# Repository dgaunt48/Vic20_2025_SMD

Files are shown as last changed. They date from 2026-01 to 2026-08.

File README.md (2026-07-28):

# Vic20_2025_SMD
Vic20 Recreation using only parts currently manufactured.

NOTE: Original (PAL) VIC chip is still required in first prototype, will be optional in next revision.

## First Prototype Boards
Hooked up the test harness and passed all tests in DiagROM.

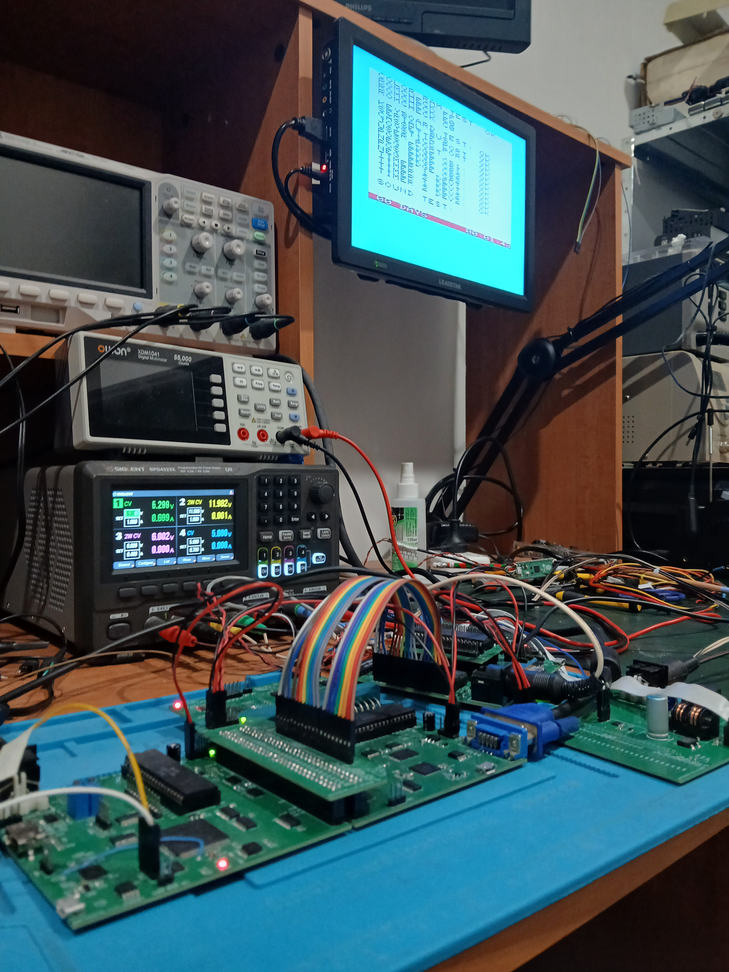
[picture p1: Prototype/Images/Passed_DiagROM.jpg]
Passed DiagROM Passed Diag ROM


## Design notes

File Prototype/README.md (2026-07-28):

# Vic20_2025_SMD_PROTOTYPE

## Added VIA 6522 to FPGA.
Hacked the hell out of the I/O board (all that mess on the left) to interface with an iCE40 FPGA. There should be just enough pins to add both VIA's to the $10 iCE40 that forms the core of this build.  Only VIA 2 (the keyboard scan and serial edge triggers) is running on the FPGA at the moment. A Real 6522 VIA (near the serial connector) is working together nicely with the FPGA VIA core to complete the serial I/O.

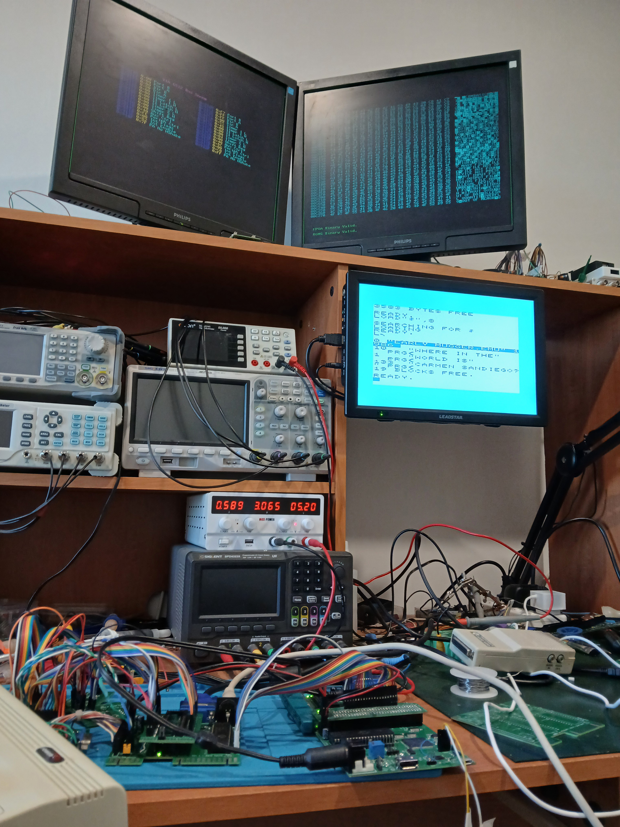
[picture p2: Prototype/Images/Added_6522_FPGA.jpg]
New VIA Core


## First Prototype Board.
RP2350A is only there as a HDMI encoder.
ICE40 FPGA has main 5k RAM, Colour RAM, Character ROM and all glue logic.
RP2350B configures FPGA core and 128k RAM chip used For Expansion RAM / ROM on 6502 Side Of Bus.  RAM IC gets copys of ROMS (including KERNAL and BASIC) before banking and R/W access is enforced.  

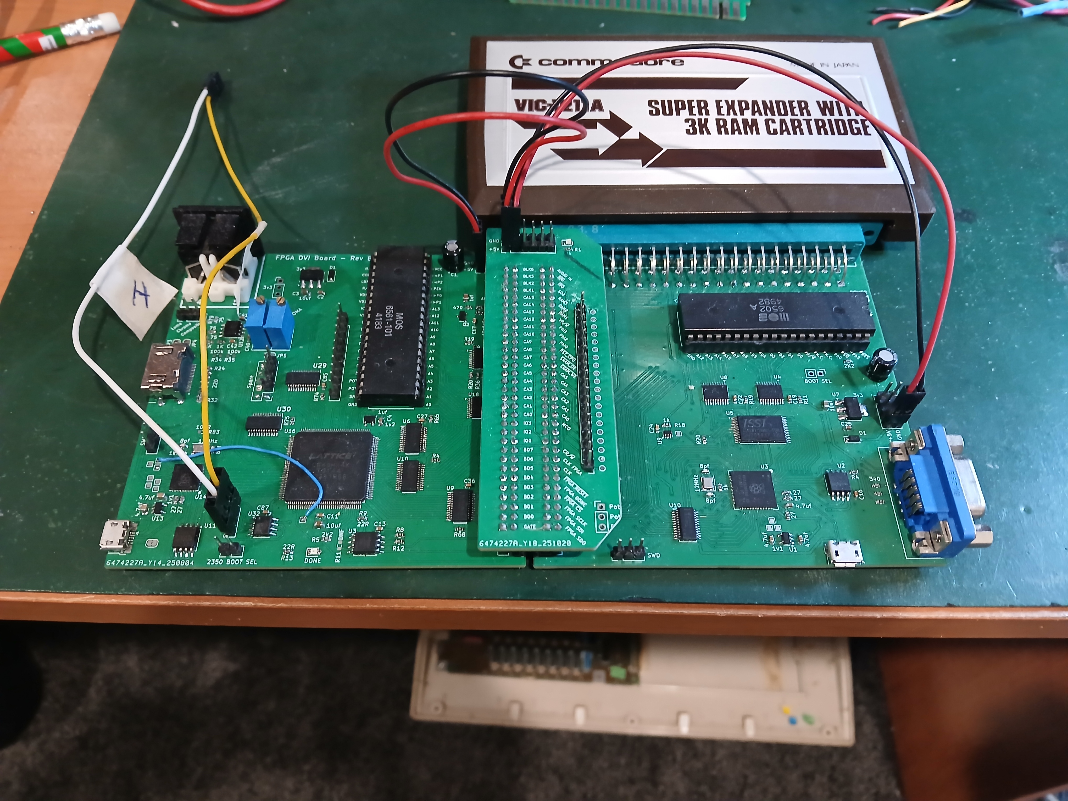
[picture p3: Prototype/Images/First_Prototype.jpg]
First Prototype First Prototype Board


## First Experiments With The Vic20

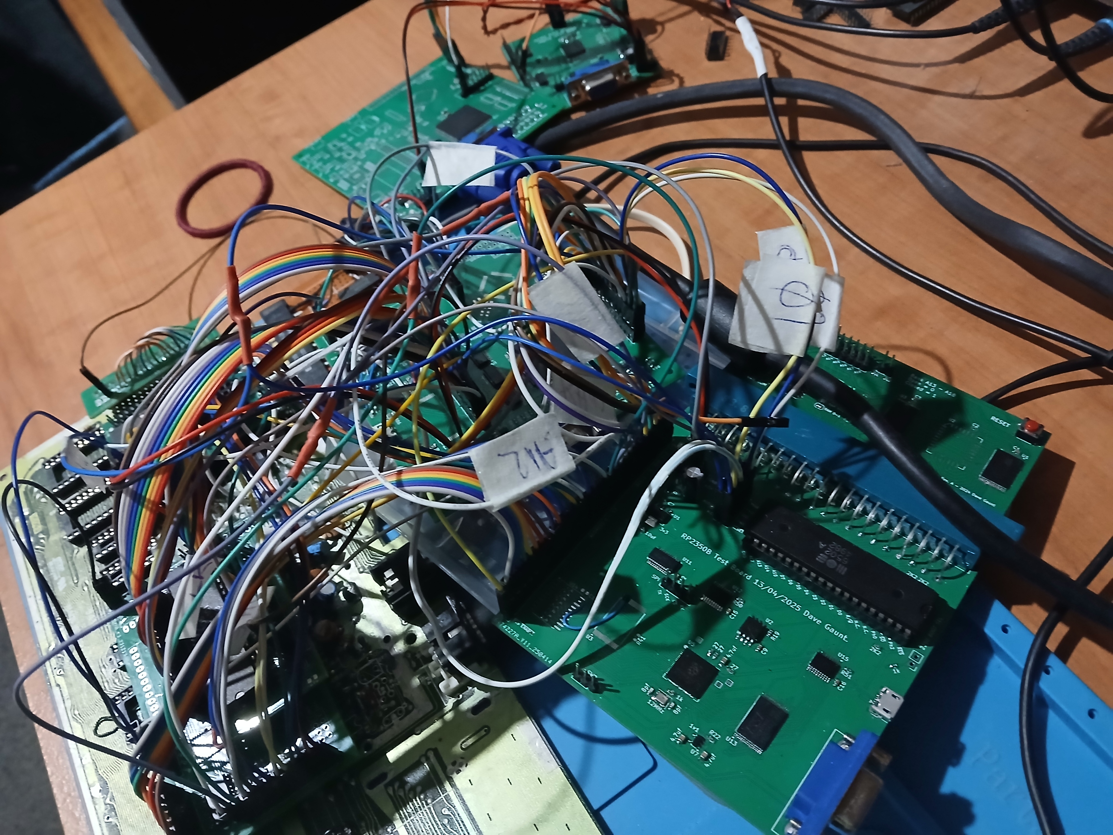
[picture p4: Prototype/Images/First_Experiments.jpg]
First Experiments First Experiments With The Vic20


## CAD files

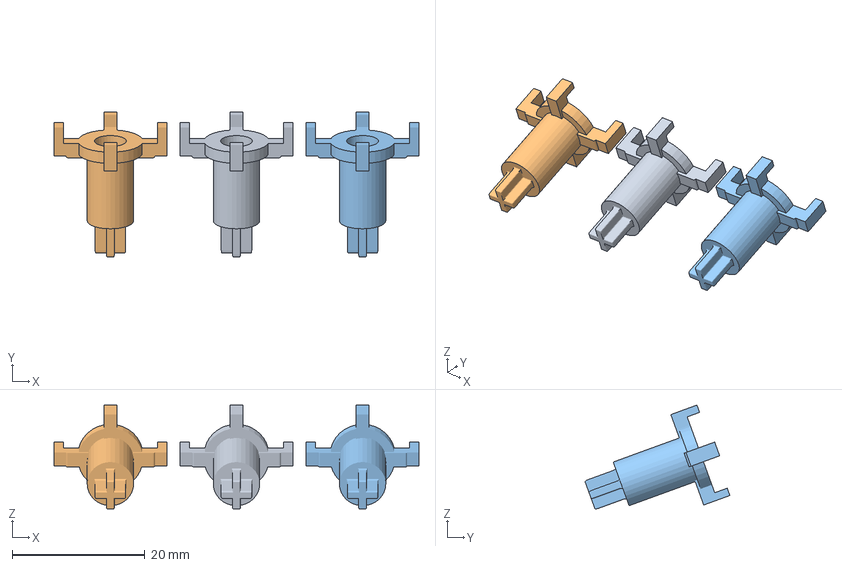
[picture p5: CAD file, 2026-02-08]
3d Prints/Vic20CR_KeyStem/CE3S1PRO_KeyStem_Vic20CR_NoSpring.3mf
55.0 x 21.8 x 15.7 mm
KeyStem_Vic20_CR_NoSprings.stl
KeyStem_Vic20_CR_NoSprings.stl(1)
KeyStem_Vic20_CR_NoSprings.stl(2)

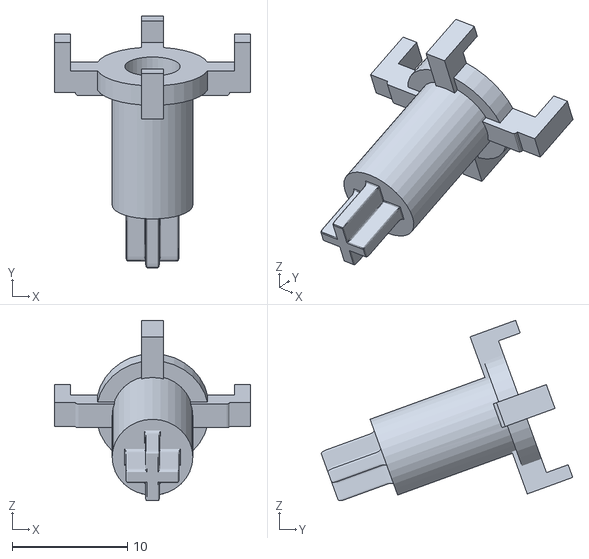
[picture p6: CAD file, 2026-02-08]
3d Prints/Vic20CR_KeyStem/KeyStem_Vic20CR_NoSpring.stl
17.0 x 21.8 x 15.7

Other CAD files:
3d Prints/Vic20CR_KeyStem/Vic20_KeyStem.blend

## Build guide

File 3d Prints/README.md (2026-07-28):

# Vic20CR_KeyStem
3D printed key stem for Vic20 CR (no spring version)

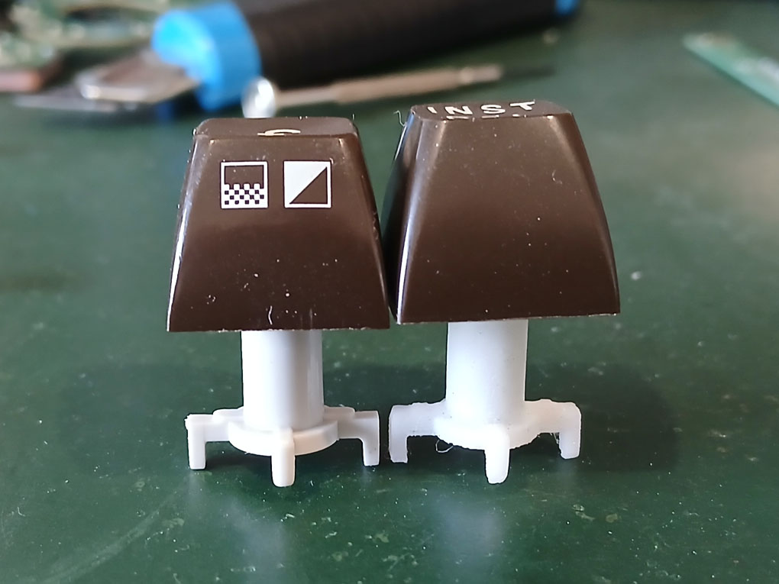
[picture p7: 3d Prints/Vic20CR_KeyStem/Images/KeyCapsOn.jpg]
KeyCaps Key Caps On


Comparison:  Original on Left / 3d Print On Right.

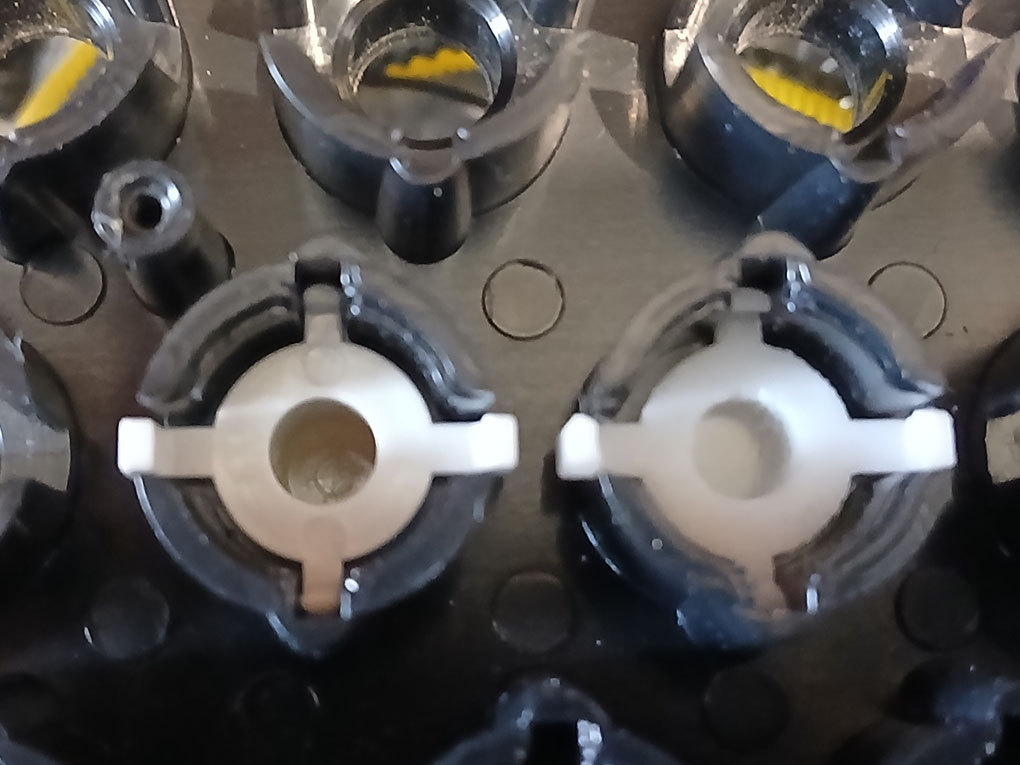
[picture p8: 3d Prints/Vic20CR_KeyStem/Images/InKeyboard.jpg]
KeyBoard In Keyboard


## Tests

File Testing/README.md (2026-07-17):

# Source Code For Vic 20 SMD Recreation
VIA 6522 FPGA Core is now running and passing the diagnostic cartridge tests.

## DiagnosticROM
Cut down diagnostic 6502 source so i can target individual test conditions.  Full Source 
to vc-20-diag.324173-01_blk5.bin is in my CBM_Flash_ROMs\Vic20_DiagROM repository.

## VIA_6522_Emulation
Start of a software emulated 6522.  Will probably end up with the VIA's on the iCE40,
but wanted to do some tests to see if emulation is a viable alternative.

## VIA_6522_Snoop
Rp2350 Bus Snoop program to display all register reads and writes to both VIA IC's on a running Vic20.

## VIA_6522_Tester
RP2350 program to bitbang test conditions into a real 6522.  At the moment it is
only setting up timer 1 to loop forever, triggering IRQ interrupts every 6 clocks.

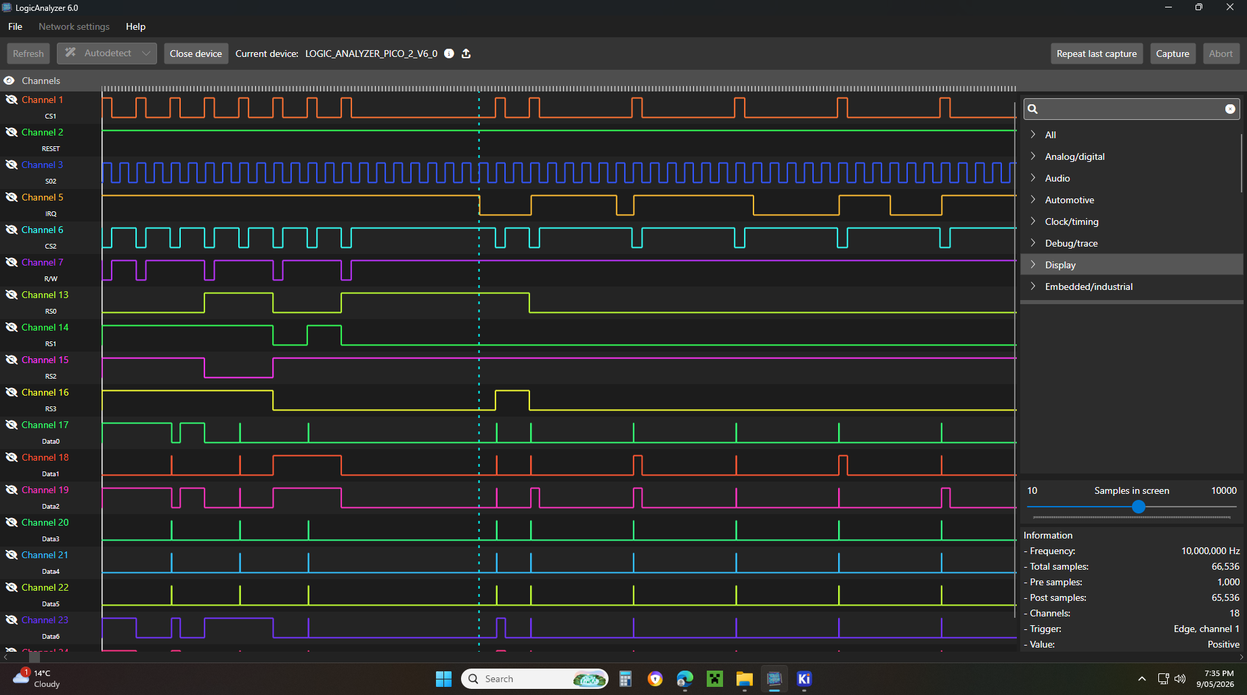
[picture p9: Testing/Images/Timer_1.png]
6522 Running Timer 1


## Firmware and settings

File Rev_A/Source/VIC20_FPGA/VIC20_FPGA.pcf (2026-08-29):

set_io bPhase2Clock			1		# Vic20 1,108,404 Hz clock
set_io bRead				3		# Read = 1 / Write = 0
set_io bCS_n				7		# Chip Select Active Low
set_io bCA1					2
set_io bCB1					4

set_io nRS[0]				73		# 4 Bit Register Address
set_io nRS[1]				75
set_io nRS[2]				78
set_io nRS[3]				80
# set_io bCS				82		# nRS[4]  Chip Select Active Hi
set_io bCS					83		# nRS[5]  Chip Select Active Hi

set_io bFPGACoreClock		93		# 25Mhz FPGA Clock

set_io nData[0]				97		# 8 Bit Data Bus
set_io nData[1]				99
set_io nData[2]				102
set_io nData[3]				105
set_io nData[4]				107
set_io nData[5]				110
set_io nData[6]				106
set_io nData[7]				104

set_io bCA2					112
set_io bCB2					114
set_io bIRQ_n				119		# IRQ_n Active Low Open Drain IRQ Signal
set_io bReset_n				117		# Reset VIA Active Low

set_io nPortA[0]			120		# 8 Bit IO Data Port A
set_io nPortA[1]			122
set_io nPortA[2]			125
set_io nPortA[3]			134
set_io nPortA[4]			135
set_io nPortA[5]			130
set_io nPortA[6]			124
set_io nPortA[7]			121

set_io nPortB[0]			136		# 8 Bit IO Data Port B
set_io nPortB[1]			138
set_io nPortB[2]			141
set_io nPortB[3]			143
set_io nPortB[4]			144
set_io nPortB[5]			142
set_io nPortB[6]			139
set_io nPortB[7]			137

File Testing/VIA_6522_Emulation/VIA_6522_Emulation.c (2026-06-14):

//------------------------------------------------------------------------------------------------
//---- VIA 6522 ... 2026 Dave Gaunt                                                           ----
//------------------------------------------------------------------------------------------------
//---- Version 0.1                                                                            ----
//------------------------------------------------------------------------------------------------
#include <stdio.h>
#include "types.h"
#include "pico/stdlib.h"
#include "pico/multicore.h"

#include "vga111.h"

enum device_pins {
	PIN_RED = 0,
	PIN_GREEN,
	PIN_BLUE,
	PIN_S02_READ,
	PIN_HSYNC = 8,
	PIN_VSYNC,

	PIN_RESET,
	PIN_ADDRESS_CS1,		/* ADDRESS BIT 4 OR 5 On VIC */
	PIN_IO0,				/* CS2 ACTIVE LOW */
	PIN_READ_WRITE,
	PIN_IRQ,

	PIN_DATA_BIT0,
	PIN_DATA_BIT1,
	PIN_DATA_BIT2,
	PIN_DATA_BIT3,
	PIN_DATA_BIT4,
	PIN_DATA_BIT5,
	PIN_DATA_BIT6,
	PIN_DATA_BIT7,

	PIN_CLK,				/* S02 - Data Transfer Occurs Only When Phase 2 Clock Is High */
	PIN_ADDRESS_BIT0,
	PIN_ADDRESS_BIT1,
	PIN_ADDRESS_BIT2,
	PIN_ADDRESS_BIT3,

	PIN_PORT_A = 32,
	PIN_PORT_B = 40
};

static_assert(23 == PIN_CLK, "Clock must be on PIN 23!");

//------------------------------------------------------------------------------------------------
//----                                                                                        ----
//------------------------------------------------------------------------------------------------
enum via_register_names
{
	VIA_REG_PORTB = 0,
	VIA_REG_PORTA,
	VIA_REG_DATA_DIRB,
	VIA_REG_DATA_DIRA,
	VIA_REG_TIMER1_L,
	VIA_REG_TIMER1_H,
	VIA_REG_TIMER1_LATCH_L,
	VIA_REG_TIMER1_LATCH_H,
	VIA_REG_TIMER2_L,
	VIA_REG_TIMER2_H,
	VIA_REG_SHIFT,
	VIA_REG_AUXILIARY_CONTROL,
	VIA_REG_PERIPHERAL_CONTROL,
	VIA_REG_INTERRUPT_FLAGS,
	VIA_REG_INTERRUPT_ENABLE,
	VIA_REG_PORTA_NO_HANDSHAKE
};

// Register Name Strings For Debug View.
static const char s_aszRegisterNames[16][16] =
{
/*  "123456789ABCDEF"	*/
	"Port B",
	"Port A",
	"Dir B",
	"Dir A",
	"Timer 1 L",
	"Timer 1 H",
	"T1 Latch L",
	"T1 Latch H",
	"Timer 2 L",
	"Timer 2 H",
	"Shift Reg",
	"Aux Ctrl",
	"Periph Ctrl",
	"Int Flags",
	"Int Enable",
	"PA No HShake"
/*  "123456789ABCDEF"	*/
};

enum via_irq_flags
{
	VIA_IRQ_CA2 = 0,
	VIA_IRQ_CA1,
	VIA_IRQ_SHIFT,
	VIA_IRQ_CB2,
	VIA_IRQ_CB1,
	VIA_IRQ_TIMER2,
	VIA_IRQ_TIMER1,
	VIA_IRQ_SET_CLR
};

typedef struct
{
	union
	{
		u8 m_aReg[16];
		struct
		{
			u8 m_u8PortB;					/* 0 */
			u8 m_u8PortA;					/* 1 */
			u8 m_uDataDirB;					/* 2 */
			u8 m_uDataDirA;					/* 3 */
			union
			{
				u16	m_uTimer1;
				struct
				{
					u8 m_uTimer1_L;			/* 4 */
					u8 m_uTimer1_H;			/* 5 */
				};
			};
			union
			{
				u16	m_uTimer1_Latch;
				struct
				{
					u8 m_uTimer1_Latch_L;	/* 6 */
					u8 m_uTimer1_Latch_H;	/* 7 */
				};
			};
			union
			{
				u16	m_uTimer2;
				struct
				{
					u8 m_uTimer2_L;			/* 8 */
					u8 m_uTimer2_H;			/* 9 */
				};
			};
			u8 m_uShiftReg;					/* A */
			u8 m_uAuxiliaryCtrl;			/* B */
			u8 m_uPeripheralCtrl;			/* C */
			u8 m_uInterruptFlags;			/* D */
			u8 m_uInterruptEnable;			/* E */
			u8 m_u8PortA_NoHandshake;		/* F */
		};
	};
} ViaRegisters;
static_assert(sizeof(ViaRegisters) == 16);

static volatile ViaRegisters s_viaRegs = {0};

typedef struct
{
	u8	m_uOffset;
	u8	m_uData;
} RegisterBuffer;

static volatile RegisterBuffer s_aRegBuffer[16];
static volatile u8 s_uRegHead = 15;
static volatile u8 s_uRegTail = 15;

//------------------------------------------------------------------------------------------------
//----                                                                                        ----
//------------------------------------------------------------------------------------------------
static void __not_in_flash_func(function_core1)(void)
{
	save_and_disable_interrupts();

	u32 uS02 = 1;
 	u32 uLow32Pins = gpioc_lo_in_get();

	// Wait for IO0 To Return Hi AND S02 To Assert Low
	while ( (0 == ((uLow32Pins >> PIN_IO0) & 1)) || (1 == ((uLow32Pins >> PIN_CLK) & 1)) )
		uLow32Pins = gpioc_lo_in_get();

	while(true)
 	{
		while(true)
		{
	 		uLow32Pins = gpioc_lo_in_get();

			// If S02 Is Hi
			if ((uLow32Pins >> PIN_CLK) & 1)
			{
				if (0 == uS02)
				{
					// And IO0 Is Low Then Process VIA IO
					if ((0 == ((uLow32Pins >> PIN_IO0) & 1)) && ((uLow32Pins >> PIN_ADDRESS_CS1) & 1))
						break;

						// We Have Finished For This Transition Of S02
					uS02 = 1;
				}
			}
			else
			{
				if (1 == uS02)
				{
					// S02 Has Transitioned From Hi To Low - Check If The Timer Is Non-Zero
					if (0 != s_viaRegs.m_uTimer1)
					{
						// If the Timer Will Go To Zero
						if (1 == s_viaRegs.m_uTimer1)
						{
							s_viaRegs.m_uTimer1 = s_viaRegs.m_uTimer1_Latch;
							s_viaRegs.m_uInterruptFlags |= (1 << VIA_IRQ_TIMER1);
						}
						else
						{
							s_viaRegs.m_uTimer1--;
						}
					}

					u32 uHiPins = gpioc_hi_in_get();
					s_viaRegs.m_u8PortA = (uHiPins >> (PIN_PORT_A - 32)) & 0xFF;
					s_viaRegs.m_u8PortA_NoHandshake = (uHiPins >> (PIN_PORT_A - 32)) & 0xFF;
				}

				// S02 Has Transitioned From Hi To Low
				uS02 = 0;
			}
		}

		if ( 0 == ((uLow32Pins >> PIN_READ_WRITE) & 1) )
		{
			delay_40ns();
			uLow32Pins = gpioc_lo_in_get();
			const u32 uRegister = (uLow32Pins >> PIN_ADDRESS_BIT0) & 0xF;
			const u32 uData = (uLow32Pins >> PIN_DATA_BIT0) & 0xFF;

			switch(uRegister)
			{
				case VIA_REG_PORTB:
					gpioc_hi_out_xor((gpioc_hi_out_get() ^ (uData << (PIN_PORT_B - 32))) & (0xFF << (PIN_PORT_B - 32)));
					s_viaRegs.m_u8PortB ^= (s_viaRegs.m_u8PortB ^ uData) & s_viaRegs.m_uDataDirB;
				break;

				case VIA_REG_PORTA:
					gpioc_hi_out_xor((gpioc_hi_out_get() ^ (uData << (PIN_PORT_A - 32))) & (0xFF << (PIN_PORT_A - 32)));
					s_viaRegs.m_u8PortA ^= (s_viaRegs.m_u8PortA ^ uData) & s_viaRegs.m_uDataDirA;
				break;

				case VIA_REG_DATA_DIRB:
					gpioc_hi_oe_xor((gpioc_hi_oe_get() ^ (uData << (PIN_PORT_B - 32))) & (0xFF << (PIN_PORT_B - 32)));
					s_viaRegs.m_uDataDirB = uData;
				break;

				case VIA_REG_DATA_DIRA:
					gpioc_hi_oe_xor((gpioc_hi_oe_get() ^ (uData << (PIN_PORT_A - 32))) & (0xFF << (PIN_PORT_A - 32)));
					s_viaRegs.m_uDataDirA = uData;
				break;

				default:
					// Push Register Set Onto Ring Buffer.
					const u8 uRegTail = (s_uRegTail + 1) & 15;
					assert(uRegTail != s_uRegHead);		// Ring Buffer Is Full !!!
					s_aRegBuffer[uRegTail].m_uOffset = (u8)uRegister;
					s_aRegBuffer[uRegTail].m_uData = (u8)uData;
					s_uRegTail = uRegTail;
				break;
			}

			// Wait for IO0 To Return Hi OR S02 To Assert Low
			// while ( (0 == ((uLow32Pins >> PIN_IO0) & 1)) && (1 == ((uLow32Pins >> PIN_CLK) & 1)) )
			// 	uLow32Pins = gpioc_lo_in_get();
		}
		else
		{
			const u32 uRegister = (uLow32Pins >> PIN_ADDRESS_BIT0) & 0xF;
			const u8 uData = s_viaRegs.m_aReg[uRegister];
			gpio_put_masked((0xFF << PIN_DATA_BIT0), (uData << PIN_DATA_BIT0));

			// Set All Data Bits To Output
			gpio_set_dir_masked((0xFF << PIN_DATA_BIT0), (0xFF << PIN_DATA_BIT0));

			// Wait for IO0 To Return Hi OR S02 To Assert Low
			while ( (0 == ((uLow32Pins >> PIN_IO0) & 1)) && (1 == ((uLow32Pins >> PIN_CLK) & 1)) )
				uLow32Pins = gpioc_lo_in_get();

			// Get Off The Bus
			gpio_set_dir_masked((0xFF << PIN_DATA_BIT0), 0);

			// If We Read Timer1 Low Byte Clear The IRQ Flag.
			if (VIA_REG_TIMER1_L == uRegister)
				s_viaRegs.m_uInterruptFlags &= ~(1 << VIA_IRQ_TIMER1);
		}
	}
}

//------------------------------------------------------------------------------------------------
//----                                                                                        ----
//------------------------------------------------------------------------------------------------
void ProcessVIA(void)
{
	// Are There Any Register Writes On The Ring Buffer?
	if (s_uRegHead != s_uRegTail)
	{
		const u8 uRegister = s_aRegBuffer[s_uRegHead].m_uOffset & 15;
		const u8 uData = s_aRegBuffer[s_uRegHead].m_uData;

		switch(uRegister)
		{
			case VIA_REG_TIMER1_L:
			{
				// Write Data Into The Low Order Latch... Not The Counter!!!
				s_viaRegs.m_uTimer1_Latch_L = uData;
			}
			break;

			case VIA_REG_TIMER1_H:
			{
				s_viaRegs.m_uTimer1_Latch_H = uData;
				s_viaRegs.m_uTimer1 = s_viaRegs.m_uTimer1_Latch;
				s_viaRegs.m_uInterruptFlags &= ~(1 << VIA_IRQ_TIMER1);
			}
			break;

			case VIA_REG_TIMER1_LATCH_L:
			{
				s_viaRegs.m_uTimer1_Latch_L = uData;
			}
			break;

			case VIA_REG_TIMER1_LATCH_H:
			{
				s_viaRegs.m_uTimer1_Latch_H = uData;
				s_viaRegs.m_uInterruptFlags &= ~(1 << VIA_IRQ_TIMER1);
			}
			break;

			case VIA_REG_INTERRUPT_FLAGS:
			{
				if (uData & 0x80)
				{
					// Bit 7 Is High So Enable Any Specified Interrupts.
					s_viaRegs.m_uInterruptFlags |= (uData & 0x7F);
				}
				else
				{
					// Bit 7 Is Low So Disable Any Specified Interrupts.
					s_viaRegs.m_uInterruptFlags &= (~uData & 0x7F);
				}

				if (s_viaRegs.m_uInterruptFlags)
					s_viaRegs.m_uInterruptFlags |= (1 << VIA_IRQ_SET_CLR);
			}
			break;

			case VIA_REG_INTERRUPT_ENABLE:
			{
				if (uData & 0x80)
				{
					// Bit 7 Is High So Enable Any Specified Interrupts.
					s_viaRegs.m_uInterruptEnable |= (uData & 0x7F);
				}
				else
				{
					// Bit 7 Is Low So Disable Any Specified Interrupts.
					s_viaRegs.m_uInterruptEnable &= (~uData & 0x7F);
				}
			}
			break;

			default:
			s_viaRegs.m_aReg[uRegister] = uData;
		}

		// FIXME!!!!! THIS SHOULD BE A PRE INCREMENT!!!!!
		s_uRegHead = (s_uRegHead + 1) & 15;
	}

	const u8 uInterrupFlags = s_viaRegs.m_uInterruptFlags & s_viaRegs.m_uInterruptEnable;

	// If Any Enabled Interrupt Is Flagged The Set The Hi Bit
	s_viaRegs.m_uInterruptFlags = (uInterrupFlags) ? (1 << VIA_IRQ_SET_CLR) | uInterrupFlags : 0;

	// Reflect The IRQ Bit On The IO Pin.
	gpio_put(PIN_IRQ, ((~s_viaRegs.m_uInterruptFlags >> VIA_IRQ_SET_CLR) & 1));
}

//------------------------------------------------------------------------------------------------
//----                                                                                        ----
//------------------------------------------------------------------------------------------------
int main()
{
	stdio_init_all();

	gpio_init(PIN_CLK);
	gpio_set_dir(PIN_CLK, GPIO_IN);

	// Clock Is Currently Looped Back So PIN_CLK Can Be Created And Read By The Test Program.
	gpio_init(PIN_S02_READ);
	gpio_set_dir(PIN_S02_READ, GPIO_IN);

	// CS1 Is Address Line 4 Or 5 On The VIC.
	gpio_init(PIN_ADDRESS_CS1);
	gpio_set_dir(PIN_ADDRESS_CS1, GPIO_IN);

	gpio_init(PIN_IO0);
	gpio_set_dir(PIN_IO0, GPIO_IN);

	gpio_init(PIN_READ_WRITE);
	gpio_set_dir(PIN_READ_WRITE, GPIO_IN);

	// IRQ Active Low
	gpio_init(PIN_IRQ);
	gpio_set_dir(PIN_IRQ, GPIO_OUT);
	gpio_put(PIN_IRQ, true);

	// Set All Data Pins To Input
	for(u32 uPin=PIN_DATA_BIT0; uPin<=PIN_DATA_BIT7; ++uPin)
	{
		gpio_init(uPin);
		gpio_set_dir(uPin, GPIO_IN);
	}

	// Set All Address Pins To Input
	for(u32 uPin=PIN_ADDRESS_BIT0; uPin<=PIN_ADDRESS_BIT3; ++uPin)
	{
		gpio_init(uPin);
		gpio_set_dir(uPin, GPIO_IN);
	}

	gpio_init(PIN_RESET);
	gpio_set_dir(PIN_RESET, GPIO_IN);

	for(u32 uPinIndex=0; uPinIndex<8; ++uPinIndex)
	{
		gpio_init(PIN_PORT_A + uPinIndex);
		gpio_init(PIN_PORT_B + uPinIndex);

		gpio_set_dir(PIN_PORT_A + uPinIndex, GPIO_IN);
		gpio_set_dir(PIN_PORT_B + uPinIndex, GPIO_IN);

		gpio_pull_up(PIN_PORT_A + uPinIndex);
		gpio_pull_up(PIN_PORT_B + uPinIndex);
	}

	multicore_launch_core1(function_core1);

	vga_Init(PIN_RED, PIN_HSYNC, PIN_VSYNC);
	vga_FilledRect(0, 0, VGA_RESOLUTION_X, VGA_RESOLUTION_Y, RGB111_GREEN);
	vga_FilledRect(1, 1, VGA_RESOLUTION_X-2, VGA_RESOLUTION_Y-2, RGB111_BLACK);

	// Draw All The Constant Text To The Screen
	char szTempString[128];
	vga_DrawString(20, 18, "VIA 6522", RGB111_CYAN);

	for (u32 uRegisterIndex=0; uRegisterIndex<16; ++uRegisterIndex)
	{ 
		sprintf(szTempString, "0x%04X", 0x9110 + uRegisterIndex);
		vga_DrawString(13, 20 + uRegisterIndex, szTempString, RGB111_BLUE);
		vga_DrawString(20, 20 + uRegisterIndex, "0x", RGB111_YELLOW);
		vga_DrawString(25, 20 + uRegisterIndex, s_aszRegisterNames[uRegisterIndex], RGB111_CYAN);
	}

	while(true)
	{
		// Loop For All 16 Registers
		for (u32 uRegisterIndex=0; uRegisterIndex<16; ++uRegisterIndex)
		{ 
			// Write The Register Values To The Appropriate Screen Position
			const uint16_t uHexPair = byteToHex(s_viaRegs.m_aReg[uRegisterIndex]);
			vga_DrawPetsciiChar(22 << 3, (20 + uRegisterIndex) << 3, uHexPair >> 8, RGB111_YELLOW);
			vga_DrawPetsciiChar(23 << 3, (20 + uRegisterIndex) << 3, uHexPair & 255, RGB111_YELLOW);

			// Call This Often Or The Input Buffer Will Overflow!!!
			ProcessVIA();
		}
	}
}

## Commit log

2026-02-03 - Added the prototype boards gerber files.
    [6502_RevC-B_Cu.gbl, 6502_RevC-B_Mask.gbs, 6502_RevC-B_Paste.gbp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]
2026-02-03 - Added KiCad project for prototype boards.
    [CPU_ROM.kicad_sch, VIA.kicad_sch, Vic20_2025_SMD.kicad_pcb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]
2026-02-08 - Started To Add The Framework For VIA IO Operations.
2026-02-08 - Timer 1 is now running well enough to blink the cursor without a VIA IC being present.
2026-02-08 - Moved Vic20CR KeyStem 3d Model In Here To Keep It With My Vic20 Stuff.
    [CE3S1PRO_KeyStem_Vic20CR_NoSpring.3mf, KeyStem_Vic20CR_NoSpring.stl, Vic20_KeyStem.blend]
2026-02-21 - Tested IO Expander... Don't Like It, Needs 32 Bits To Read A Register At A Max SPI Clock Speed Of 10Mhz, Thats Only 312Khz!!!
2026-05-03 - Updated to KiCad 10
    [CPU_ROM.kicad_sch, VIA.kicad_sch, Vic20_2025_SMD.kicad_pcb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]
2026-05-14 - Modified Reset To Give The FPGA Time To Copy It's BitStream, It Can't Start immediately like the real silicon.
    [VIA_6522_Tester.c]
2026-06-14 - KiCad 10
2026-06-20 - Added framework for Vic20 Diagnostic ROM Cartridge.
    [vic20-cart.cfg]
2026-07-17 - Reorganised Prototype files in preperation for the Revision A Board.
    [6502_RevC-B_Cu.gbl, 6502_RevC-B_Mask.gbs, 6502_RevC-B_Paste.gbp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]
2026-07-20 - Added iCE40 project framework to build the 6522 VIA replacement.
    [VIC20_FPGA.pcf]
2026-07-28 - Changed .pcf VIA mappings to work with my standalone prototype board.
2026-08-15 - Moved the location of a couple of the 6522 VIA pins on the FPGA.
2026-08-15 - Added the basic framework for the Rev A Schematic.
    [Vic20_2025_SMD.kicad_pcb, Vic20_2025_SMD.kicad_sch, vic20_power.kicad_sch]
2026-08-16 - As the prototype currently spans 4 boards I have decided to spin a prototype revision 2 (two board prototype set) before i commit to the final layout and design.
    [CPU_ROM.kicad_sch, VIA.kicad_sch, Vic20_2025_SMD.kicad_pcb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]
2026-08-29 - Initial component placement for protype 2, no routing done yet.
    [CPU_ROM.kicad_sch, VIA.kicad_sch, Vic20_2025_SMD.kicad_pcb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]
2026-09-04 - Added the old IO board as reference for revision 2.
    [VIA_IO.kicad_pcb, VIA_IO.kicad_sch]
2026-09-24 - Added the prototype rev2 IO Board schematic.
    [VIA_IO.kicad_pcb, VIA_IO.kicad_sch, Vic20_2025_SMD.kicad_sch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]
2026-09-28 - Initial layout of all the major components.
    [VIA_IO.kicad_pcb, VIA_IO.kicad_sch]
2026-09-28 - Reorganised the prototype IO board layout for easier routing.
    [VIA_IO.kicad_pcb, VIA_IO.kicad_sch]
2026-10-02 - Routed the new prototype 2 IO board.
    [VIA_IO.kicad_pcb, VIA_IO.kicad_sch]
